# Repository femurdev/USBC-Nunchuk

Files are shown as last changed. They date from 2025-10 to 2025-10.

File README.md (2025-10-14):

# PCnunchuck
A full start-end 3d printing project for a nunchuck using an arduino micro.
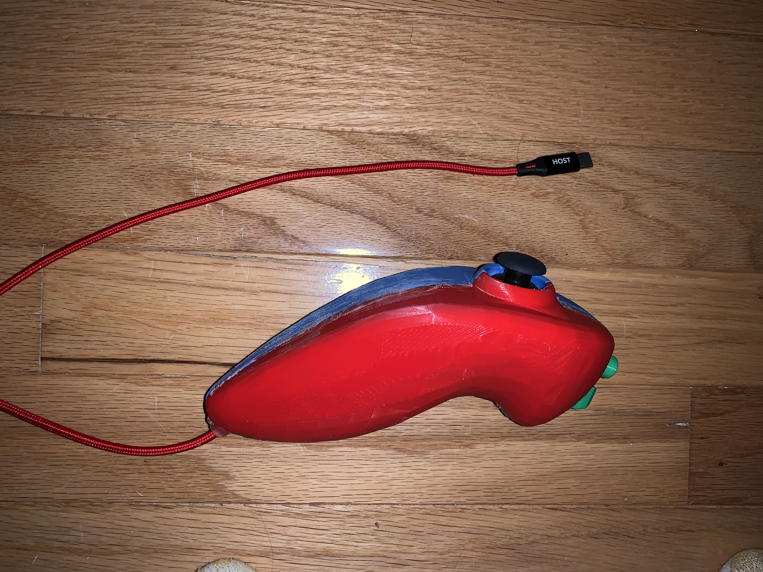
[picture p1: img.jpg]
Image of a Nintendo Switch Themed Arduino-PowerdNunchuck

- Weekly - Bi-weekly updates! (Don't quote me on this!)

# Models Exported from Blender-3.3
- Models are all very unrefined. Dremmel/sanding REQUIRED.
- Mileage/quality WILL VARRY!
- Printed on a X1C from bambu labs using Bambu labs red and green pla and matt blue.

## Parts:
- Hot glue gun
- PS3 joystick (More info avalible later)
- arduino micro
- USB-B/C to USB-B Micro cord (no, this gets used too, not just for programming arduinos)
- Two push buttons (I salvaged mine from a broken mouse) [M187](https://www.logitech.com/en-us/products/mice/m187-mini-wireless-mouse.910-005360.html) might work
- 170 pin for arduino micro Breadboard, 17x5x2
- 3 LEDS (Green, Yellow, Red)
- 220 Ohm Resistor
- One of each printed part. Look

### For The buttons:
You will need to print many of these in different scales. It varrys greatly. Sorry! Some sizes that worked for me:
- C button ~110%
- Z button ~97%

## How to put together:
You may need to dissconnect and reconnect manny things while doing this.
1. Hot hot glue top push button in place on right half.
2. Hot hot glue bottom push button in place on left half.
3. Thread the top cable up and to the verry top of the casing and behind the joystick.
4. Put the [breadboard](#Breadboard) in the right half and glue/stick/both it in place. make sure that the USB connection is facing the hole in the back. also pu this far enough forward so that you can bend the usb cable into the 5mm hole in the back of the shell. If your cabble is thicker/don't bend, sand the model down untill it exits the back.
5. Thread the bottom cable through the bottom hole on the right half.
6. Connect everything.
7. Glue the joystick in place on the Left half. Try you best to center the holes in the model with the joystick.
8. Connect the micro to your computer via the usb cable. Upload the Check.ino sketch! If everything works (buttons, joystick, leds) you did it right!
9. Keep the arduino connected and slowly close the casing. Leave about a centimeter of clearance before closing it.
10. Put the two button caps (Z and C) into place and use hot glue to hold them to the left side of the model temporarily. Make sure this is on the OUTSIDE of the shell!
11. Making sure the usb is till connected to the micro thred it through the hole in the back and glue it in place. 
12. Put glue on the joystick's oppisite side where it will cotact the model and seal it shut. 
13. Sand and dremmel any extra hot glue off the keycaps. Verrify they move and feel "clicky"
14. Glue the split arround the edge if the model.
15. Sand and dremmel any extra hot glue off the model. refine the look
16. Upload the nunchuckMicro.ino to it.
17. DONE! Submit a pull request to conttribute to the code and check back every so often for any firmware updates! You should now have a mouse/keyboard as a wii nunchuck!
### Breadboard
- Arduino uno in the center
- Connect these to these pins
    * Joystick:
        * joystick xPos --> A0
        * joystick yPos --> A1
        * joystick SW --> pin 4
        * Joystick VCC --> 5v
        * Joystick GND --> GND
    * Buttons:
        * button Z lead 1 --> pin 2
        * button Z  lead 2 --> GND
        * button C lead 1 --> pin 3
        * button C lead 2 --> GND
    * LEDS:
        * LED postive (long) leads (+):
            * Green LED --> 10
            * Yellow LED --> 11
            * Red LED --> 12
        * LED negative (short) leads (-):
        * 220 Ohm Resistor on one side
    *  220 Ohm Resistor connects one end to GND and other to all 3 LEDS

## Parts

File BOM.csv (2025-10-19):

Item | Quantity | Part Name | Description | Source / Notes | Link
1 | 1 | Arduino Micro | Main microcontroller board controlling input/output | Official Arduino or clone | https://store.arduino.cc/products/arduino-micro
2 | 1 | PS3 Joystick Module | Analog joystick with push button (X, Y, SW pins) | Common module / salvage or Amazon/eBay/Nexus | https://www.amazon.com/dp/B00PNEQKC0/
3 | 2 | Push Button Switch | Small tactile push buttons salvaged from a mouse or similar | Any small tact switch / M187 compatible | https://www.logitech.com/en-us/products/mice/m187-mini-wireless-mouse.910-005360.html
4 | 1 | Breadboard | Mini breadboard (170 pins, 17x5x2 layout) | Standard mini solderless breadboard | https://www.adafruit.com/product/65
5 | 1 | USB Cable | USB-C/B to Micro-B cable | Used for both programming and final connection | https://www.amazon.com/dp/B07G5JV2B5
6 | 3 | LED | 5 mm LEDs (Green, Yellow, Red) | Generic LEDs | https://www.adafruit.com/product/297
7 | 1 | Resistor | 220 Ω resistor | Used to limit current to LEDs | https://www.digikey.com/en/products/detail/yageo/MFR-25FBF52-220R/2058889
8 | 1 | Hot Glue Gun | Used for assembly and structural bonding | Any standard hot glue gun with glue sticks | https://www.amazon.com/dp/B000NPIMW8
9 | 1 | Set of 3D Printed Parts | All shell and button components printed from STL files in repo | Printed in PLA on Bambu Lab X1C | https://github.com/femurdev/USBC-Nunchuk
10 | 1 | USB Port Cutout Assembly | Printed slot for USB access / integration with micro board | Part of 3D model set (not purchased) | https://github.com/femurdev/USBC-Nunchuk

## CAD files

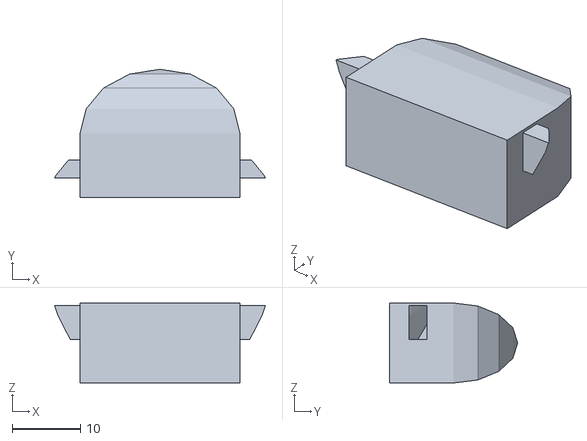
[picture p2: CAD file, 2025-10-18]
nunchuckFarmer-Z.stl
30.9 x 18.8 x 11.7

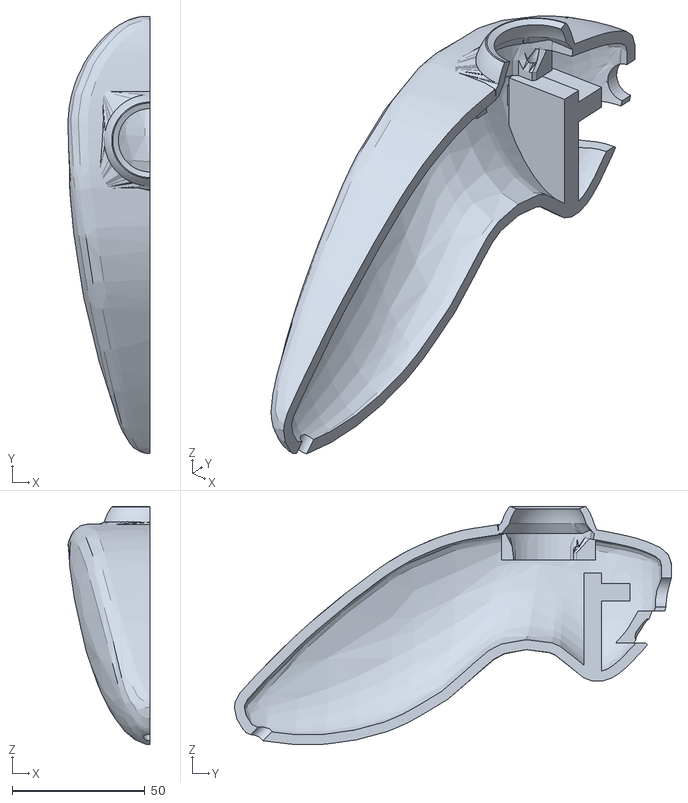
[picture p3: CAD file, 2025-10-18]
nunchuckFarmer-leftStick.stl
30.8 x 164.4 x 89.5

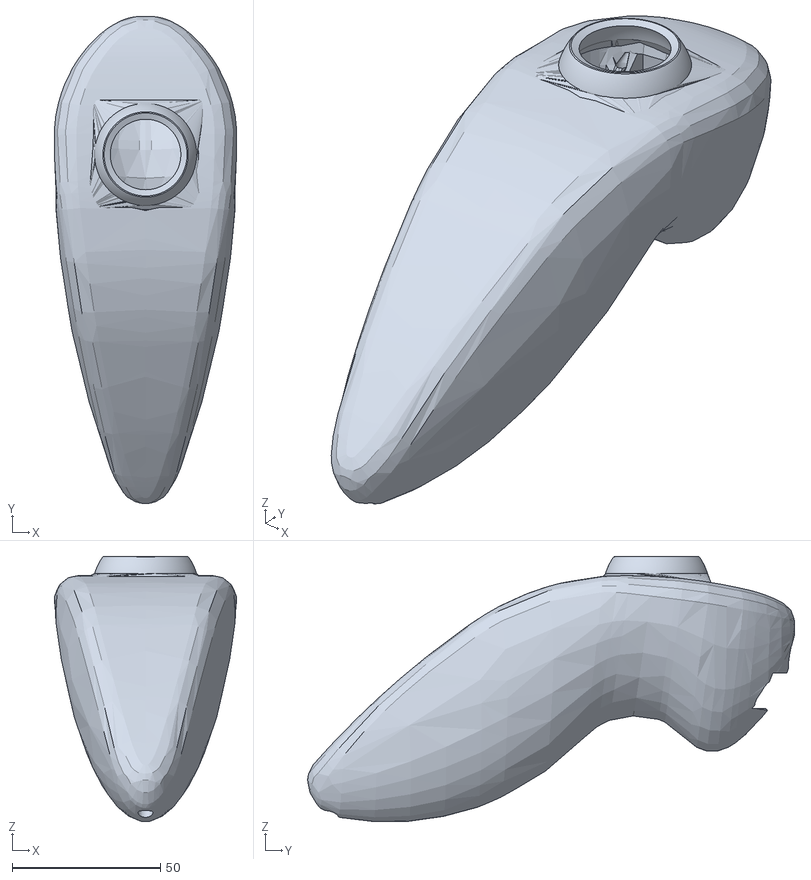
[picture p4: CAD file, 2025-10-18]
nunchuckFarmer-Fake_Wii_Nunchuck.stl
61.6 x 164.4 x 89.5

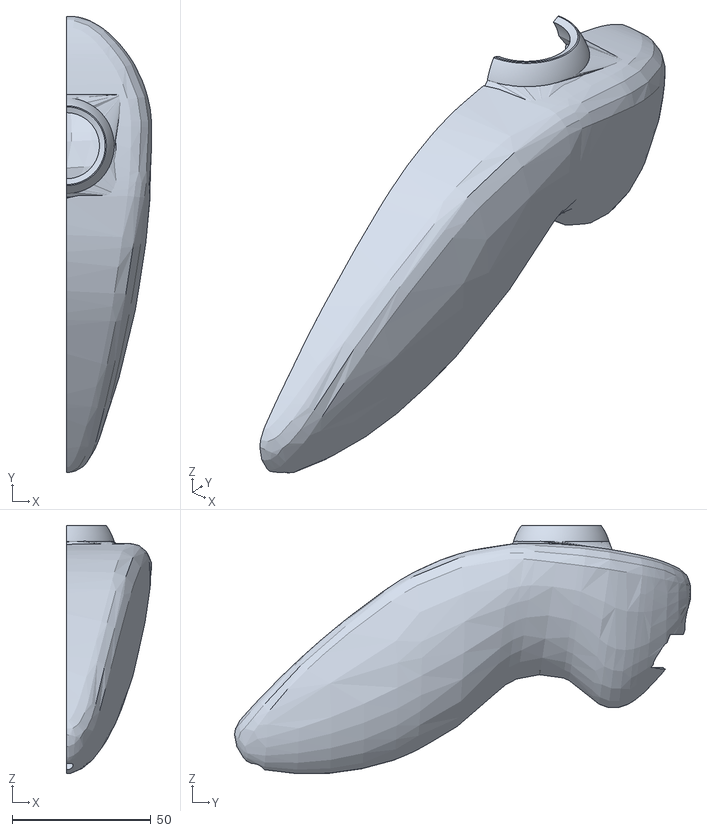
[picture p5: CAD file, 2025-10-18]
nunchuckFarmer-rightStick.stl
30.8 x 164.4 x 89.5

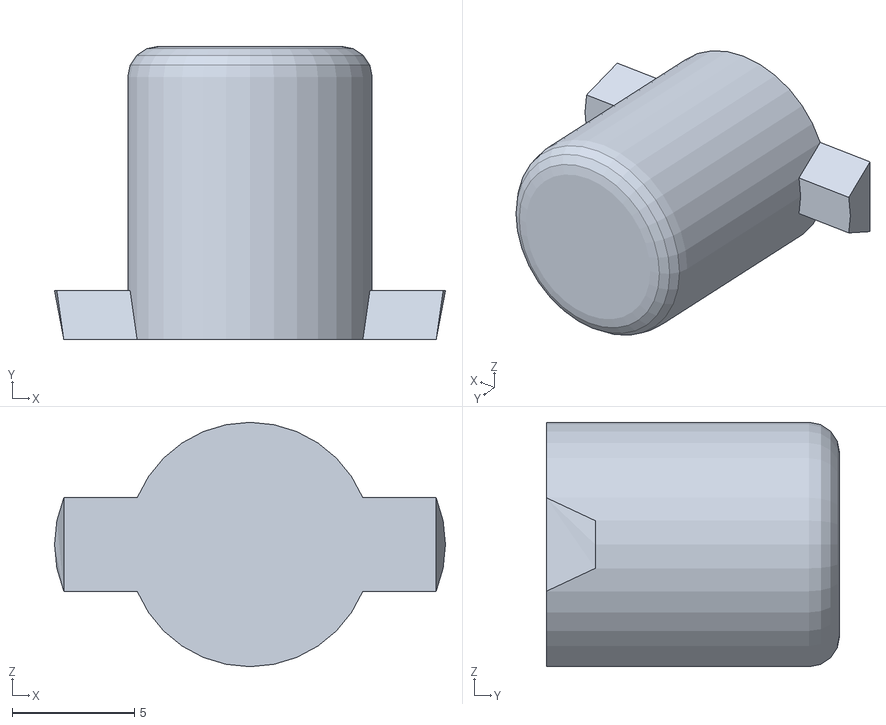
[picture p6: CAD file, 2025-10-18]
nunchuckFarmer-C.stl
16.0 x 12.0 x 10.00

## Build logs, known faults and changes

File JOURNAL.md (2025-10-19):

<!--
  ===================    !!READ THIS NOTICE!!   ====================
  DO NOT edit this file manually. Your changes WILL BE OVERWRITTEN!
  This journal is auto generated and updated by Hack Club Blueprint.
  To edit this file, please edit your journal entries on Blueprint.
  ==================================================================
-->

This is my journal of the design and building process of **USBC Nunchuck**.  
You can view this journal in more detail on **Hack Club Blueprint** [here](https://blueprint.hackclub.com/projects/524).

## 10/15/2025 - Idiazation & proof of concept  

Had to find an old nunchuk to see what it actually had on it. It has two buttons and a joystick (two potentiometers). I recreated it in tinkercad and threw together some quick code for it. The image is below.
Screenshot 2025-10-15 at 9.15.24 AM.png
I already have all of these components from a birthday present, so I don't need funding on this one.  

## 10/18/2025 - BOM and other things  

Copied some 3d scans into blender, then brushed up some things. I sketched some basic printouts and buttons, I don't intend for this thing to be glamorous, just functional. I got my supplies together today. They include:

- 1 of those joy cons that break constantly
- 1 LED
- Resistors for that LED
- 2 buttons from an old mouse

I took the measurements, then threw them out the window and eyeballed it. I don't have a ton of time, so I just gunned it to the finish line for the CAD design phase.
Here's what I have:
Screenshot 2025-10-18 at 6.55.25 PM.png

## 10/19/2025 8 AM - Fabed and Finished  


### Fab
I printed the left half on an X1, hot glued in the buttons & joy stick into position, put the 3d printed buttons into place, ran a USBC cable out the back, then glued the right half onto it.
### Code
I wrote some code, now it is finished. Not much else to say, it works like a charm except if I redid it I would have used actual buttons. There's got to be a better way.
Other than that, I printed, designed, and coded it. My ADHD won't allow me to revisit this for a bit. Everything just kinda worked. Don't ask me to take it apart, there's too much glue!
### Function
I can press on both the Z and C buttons to change it into a pointer controller for my computer. The other mode is a wasd controller for games and stuff. Pressing the joy stick jumps and z and c are left and right click respectively.  

## 10/19/2025 1 PM - Slight Recode  

I recorded some things in a second CPP file that is now on the repo, go check it out! Please leave feedback or email me at femurdev@gmail.com if you make one of these! You van make one with an Arduino micro, a USB Cable, hot glue, and one of the generic kits like the one below:


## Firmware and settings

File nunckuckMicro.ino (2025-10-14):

#include <Keyboard.h>
#include <Mouse.h>

// Constants for joystick and button pins
const int joyXPin = A0;
const int joyYPin = A1;
const int joyButtonPin = 4;
const int buttonZ = 2;
const int buttonC = 3;

// Joystick deadzone and sensitivity settings
const int deadZone = 16;
const int maxZone = 12;
const float sensitivity = 1.0f;
const float joySlope = 1.5;
const int triggerPoint = 200;

// Mouse wheel control settings
const int wheelPerc = 1024;
const int timeBetweenPoll = 5;
const int timeBetweenPollWheel = 10;

// LED pins for different modes
const int greenLED = 10;
const int yellowLED = 11;
const int redLED = 12;

// LED blinking duration
const int ledTime = 100;

// Variables for mode handling and key presses
int mode = 1; // change for startup mode
const int modes = 2;
unsigned long modeChangeStartTime = 0;
bool zWasPressed = false;
bool cWasPressed = false;
bool joyWasPressed = false;

// Key-press tracking for WASDCZ mode
bool wKeyWasPressed = false;
bool aKeyWasPressed = false;
bool sKeyWasPressed = false;
bool dKeyWasPressed = false;
bool zKeyWasPressed = false;
bool cKeyWasPressed = false;
bool spacebarKeyWasPressed = false;

void setup() {
  Keyboard.begin();
  Mouse.begin();
  Serial.begin(9600);

  pinMode(buttonZ, INPUT_PULLUP);
  pinMode(buttonC, INPUT_PULLUP);
  pinMode(joyButtonPin, INPUT_PULLUP);

  // Set LED pins as OUTPUTd
  pinMode(greenLED, OUTPUT);
  pinMode(yellowLED, OUTPUT);
  pinMode(redLED, OUTPUT);

  // Initialize LEDs to OFF state
  digitalWrite(greenLED, LOW);
  digitalWrite(yellowLED, LOW);
  digitalWrite(redLED, LOW);
  controlLEDs();
}

// Function to apply deadzone and maximum values to joystick input
int applyDeadAndMax(int value) {
  value = value - 512;
  if (abs(value) < deadZone) {
    return 0;
  } else if (value > 512 - maxZone) {
    return 512;
  } else if (value < -512 + maxZone) {
    return -512;
  }
  return value;
}

// Functions to read joystick input
int joystickHoriz() {
  return applyDeadAndMax(analogRead(joyXPin));
}

int joystickVert() {
  return applyDeadAndMax(analogRead(joyYPin));
}

// Functions to check button states
bool joyPressed() {
  return !digitalRead(joyButtonPin);
}

bool zPressed() {
  return !digitalRead(buttonZ);
}

bool cPressed() {
  return !digitalRead(buttonC);
}

// Function to map joystick input in an exponential manner
int mapExponential(int value) {
  return getSign(value) * constrain(round(pow(abs(value) / 128.0, joySlope) * 128.0), -128, 128);
}

void releaseKey(char c){
    if (cKeyWasPressed && (c == 'c')){
    Keyboard.release('C');
    cKeyWasPressed = false;
  }
  if (zKeyWasPressed && (c == 'z')){
    Keyboard.release('Z');
    zKeyWasPressed = false;
  }
  if (wKeyWasPressed && (c == 'w')){
    Keyboard.release('w');
    wKeyWasPressed = false;
  }
  if (aKeyWasPressed && (c == 'a')){
    Keyboard.release('a');
    aKeyWasPressed = false;
  }
  if (sKeyWasPressed && (c == 's')){
    Keyboard.release('s');
    sKeyWasPressed = false;
  }
  if (dKeyWasPressed && (c == 'd')){
    Keyboard.release('d');
    dKeyWasPressed = false;
  }
  if (spacebarKeyWasPressed && (c == ' ')){
    Keyboard.release(' ');
    spacebarKeyWasPressed = false;
  }
}

// Function to determine the sign of a value
int getSign(int value) {
  if (value > 0) {
    return 1; // Positive
  } else if (value < 0) {
    return -1; // Negative
  } else {
    return 0; // Zero
  }
}

// Function to control LEDs based on the current mode
void controlLEDs() {
  digitalWrite(greenLED, LOW);
  digitalWrite(yellowLED, LOW);
  digitalWrite(redLED, LOW);

  // Blink the LEDs to indicate the mode number (mode + 1)
  for (int i = 0; i < mode + 1; i++) {
    digitalWrite(greenLED, HIGH);
    digitalWrite(yellowLED, HIGH);
    digitalWrite(redLED, HIGH);
    delay(ledTime); // Blink for ledTime milliseconds
    digitalWrite(greenLED, LOW);
    digitalWrite(yellowLED, LOW);
    digitalWrite(redLED, LOW);
    delay(ledTime); // Wait for ledTime milliseconds
  }

  // Keep the corresponding LED on based on the current mode
  if (mode == 0) {
    digitalWrite(redLED, HIGH);
  } else if (mode == 1) {
    digitalWrite(yellowLED, HIGH);
  } else if (mode == 2) {
    digitalWrite(greenLED, HIGH);
  }
}

void loop() {
  // Check for mode switch
  if (joyPressed() && zPressed() && cPressed()) {
    if (modeChangeStartTime == 0) {
      modeChangeStartTime = millis();
    } else {
      if (millis() - modeChangeStartTime > 3000) {
        mode = (mode == modes - 1) ? 0 : mode + 1;
        modeChangeStartTime = 0;
        Serial.println(mode);
        controlLEDs(); // Update LEDs to reflect the new mode
        Mouse.release(MOUSE_LEFT);
        Mouse.release(MOUSE_RIGHT);
        Mouse.release(MOUSE_MIDDLE);
        Keyboard.releaseAll();
      }
    }
  } else if (modeChangeStartTime != 0) {
    modeChangeStartTime = 0;
  }

  // Handle different modes
  if (mode == 0) {
    // Mode 0: Mouse control
    if (cPressed() && joyPressed()) {
      // Scroll
      Mouse.move(0, 0, mapExponential(-joystickVert() / wheelPerc));
      delay(timeBetweenPollWheel);
      return;
    } else {
      int xOffset = mapExponential(joystickHoriz() / 16);
      int yOffset = mapExponential(joystickVert() / 16);
      Mouse.move(xOffset, -yOffset); // Invert Y-axis for typical mouse movement
    }
    // Mouse button clicks
    if (cPressed() && !cWasPressed) {
      cWasPressed = true;
      Mouse.press(MOUSE_LEFT);
    }
    if (cWasPressed && !cPressed()) {
      cWasPressed = false;
      Mouse.release(MOUSE_LEFT);
    }
    if (zPressed() && !zWasPressed) {
      zWasPressed = true;
      Mouse.press(MOUSE_RIGHT);
    }
    if (zWasPressed && !zPressed()) {
      zWasPressed = false;
      Mouse.release(MOUSE_RIGHT);
    }
    if (joyPressed() && !joyWasPressed) {
      joyWasPressed = true;
      Mouse.press(MOUSE_MIDDLE);
    }
    if (joyWasPressed && !joyPressed()) {
      joyWasPressed = false;
      Mouse.release(MOUSE_MIDDLE);
    }
  } else if (mode == 1) {
    // Mode 1: WASDCZ control
    int xOffset = 0;
    int yOffset = 0;

    int horiz = joystickHoriz();
    int vert = joystickVert();

    // horiz wins
    // Serial.print("hoiz greater: ");
    // Serial.print(abs(horiz)>abs(vert));
    // Serial.print("\t");
    // Serial.print(abs(horiz));
    // Serial.print(" > ");
    // Serial.println(abs(vert));
    // if A isn't pressed, press it
    if (!aKeyWasPressed && abs(horiz)>triggerPoint && getSign(horiz) == -1){
      Keyboard.press('a');
      aKeyWasPressed = true;
      releaseKey('d');
    }
    // if D isn't pressed, press it
    else if (!dKeyWasPressed && abs(horiz)>triggerPoint&& getSign(horiz) == 1){
      Keyboard.press('d');
      dKeyWasPressed = true;
      releaseKey('a');
    } else if (abs(horiz)<triggerPoint) {
      releaseKey('a');
      releaseKey('d');
    }
    // vert wins
    // Serial.print("vert greater: ");
    // Serial.print(abs(horiz)>abs(vert));
    // Serial.print("\t");
    // Serial.print(abs(horiz));
    // Serial.print(" < ");
    // Serial.println(abs(vert));

    // if W isn't pressed, press it
    if (!wKeyWasPressed && abs(vert)>triggerPoint && getSign(vert) == 1){
      Keyboard.press('w');
      wKeyWasPressed = true;
      releaseKey('s');
    } 
    // if S isn't pressed, press it
    else if (!sKeyWasPressed && abs(vert)>triggerPoint && getSign(vert) == -1){
      Keyboard.press('s');
      sKeyWasPressed = true;
      releaseKey('w');
    } else if (abs(vert)<triggerPoint) {
      releaseKey('w');
      releaseKey('s');
    }
    
    // if (horiz==0 && vert==0) {
    //   Keyboard.releaseAll();
    // }
  }
  if (joyPressed() && !joyWasPressed) {
      joyWasPressed = true;
      Keyboard.press(' ');
      spacebarKeyWasPressed = true;
      
    }
    if (joyWasPressed && !joyPressed()) {
      joyWasPressed = false;
      Keyboard.release(' ');
      spacebarKeyWasPressed = false;
    }

    if (zPressed() && !zWasPressed) {
      zWasPressed = true;
      Keyboard.press('z');
      zKeyWasPressed = true;
      
    }
    if (zWasPressed && !zPressed()) {
      zWasPressed = false;
      Keyboard.release('z');
      zKeyWasPressed = false;
    }

    if (cPressed() && !cWasPressed) {
      cWasPressed = true;
      Keyboard.press('c');
      cKeyWasPressed = true;
      
    }
    if (cWasPressed && !cPressed()) {
      cWasPressed = false;
      Keyboard.release('c');
      cKeyWasPressed = false;
    }
    Serial.println(cPressed());

  delay(timeBetweenPoll);
}

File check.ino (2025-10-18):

#include <Keyboard.h>
#include <Mouse.h>

const int deadZone = 24;
const int maxZone = 12;
const int joyXPin = A0;    // Analog pin for X-axis of the joystick
const int joyYPin = A1;    // Analog pin for Y-axis of the joystick
const int joyButtonPin = 4; // Digital pin for the joystick button
const int button1 = 2;
const int button2 = 3;
const int mode = 0;
const int greenLED = 10;
const int yellowLED = 11;
const int redLED = 12;
// mode, 0 = "mouse", joystick is mouse and joystick click is middle click. Button 1 = left click, Button 2 = right click
// mode, 1 = "wasd", joystick is wasd, mouse buttons are same.
// mode, 2 = "wasdcz", joystick is wasd, button 1 is c, button 2 is z, joystick is " "
// clicking and holding all buttons for 3 second changes mode

void setup() {
  // Initialize the Keyboard and Mouse libraries
  Keyboard.begin();
  Mouse.begin();
  Serial.begin(9600);
  pinMode(button1, INPUT_PULLUP);
  pinMode(button2, INPUT_PULLUP);
  pinMode(joyButtonPin, INPUT_PULLUP); // Set the joystick button pin as input with an internal pull-up resistor
  pinMode(greenLED, OUTPUT);
  pinMode(yellowLED, OUTPUT);
  pinMode(redLED, OUTPUT);
}
int applyDeadAndMax(int value){
  value = value-512;
  if (abs(value)<deadZone){
    return 512;
  } else if (value>1023-maxZone){
    return 1023;
  } else if (abs(value)<maxZone){
    return 0;
  }
  return value+512;
}
int joystickHoriz() {
  return applyDeadAndMax(analogRead(joyXPin));
}

int joystickVert() {
  return applyDeadAndMax(analogRead(joyYPin));
}

bool joyPressed() {
  return !digitalRead(joyButtonPin); // Corrected the function and added '!' to invert the button state
}
bool onePressed() {
  return !digitalRead(button1);
}
bool twoPressed() {
  return !digitalRead(button2);
}

void loop() {
  // Read joystick values
  int xValue = joystickHoriz();
  int yValue = joystickVert();

  // Print joystick and button state
  Serial.print("X-Axis: ");
  Serial.print(xValue);
  Serial.print("\tY-Axis: ");
  Serial.print(yValue);
  Serial.print("\tButton: ");
  Serial.print(joyPressed() ? "Pressed" : "Released");
  Serial.print("\tButton1: ");
  Serial.print(onePressed() ? "Pressed" : "Released");
  Serial.print("\tButton2: ");
  Serial.println(twoPressed() ? "Pressed" : "Released");

  // Perform actions based on joystick and button state
  // Here you can add logic to send keyboard and mouse input based on joystick/button state
  // For example:
  if (xValue < 400) {
    // Keyboard.write('A'); // Send 'A' when joystick is moved to the left
    // Turn on the green LED and wait for a short moment
  digitalWrite(greenLED, HIGH);
  delay(100); // 100 milliseconds (0.1 second) delay

  // Turn off the green LED
  digitalWrite(greenLED, LOW);
  delay(50); // 50 milliseconds (0.05 second) delay

  // Turn on the yellow LED and wait for a short moment
  digitalWrite(yellowLED, HIGH);
  delay(100); // 100 milliseconds (0.1 second) delay

  // Turn off the yellow LED
  digitalWrite(yellowLED, LOW);
  delay(50); // 50 milliseconds (0.05 second) delay

  // Turn on the red LED and wait for a short moment
  digitalWrite(redLED, HIGH);
  delay(100); // 100 milliseconds (0.1 second) delay

  // Turn off the red LED
  digitalWrite(redLED, LOW);
  delay(50); // 50 milliseconds (0.05 second) delay
  }


  // You can add more logic for different joystick positions and button states

  
}
